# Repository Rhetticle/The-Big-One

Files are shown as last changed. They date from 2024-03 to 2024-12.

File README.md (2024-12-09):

# The Big One

image0 (6)

https://github.com/user-attachments/assets/869daa6d-89cc-4672-a1f7-7d603dca1637

3D printed 3-stage 1kJ projectile accelerator.

## Update
As of Febuary 2024, this device is no longer operational and has been salvaged for parts.
## Safety Notice
* This device was built purely to challenge myself with a complex engineering project to learn about electronics and was never intended to be used as a weapon
* Certain parts of the build have been omitted from the repository to prevent those with malicious intent from replicating this device
## Performance
* Peak exit velocity (All capacitors charged to 385V) - 61 km/h
* Peak exit energy (100g projectile) - 13.9 J
* Efficiency - 1.4%

## Hardware Details
All circuitry and PCBs were custom made, designed in Kicad and manufactured by JLCPCB with hardware provided by Digikey or homemade (e.g. transformer, power inductors etc)
### Capacitors
The Big One uses three 4.5mF 400V chassis mount capacitors. The total energy in these capacitors at max operating voltage (385V) is approximately 1kJ. 
### Capacitor Charger
Capacitors were charged using a ZVS circuit driving a homemade step-up transformer (see below) to increase the 30VAC across the resonant capacitors of the ZVS up to 550VAC to be used to charge the high voltage capacitors. The average power output of this charger was around 300W when charging the entire bank of capacitors from 0V to 385V. 




### Control Board
The control board was mounted in the middle section. It uses an STM32F401RBT6 to control the timing of the three acceleration stages as well as measures the capacitor bank voltage. Four schottky diodes are also on the board to rectify the transformer output.

image0 (10)

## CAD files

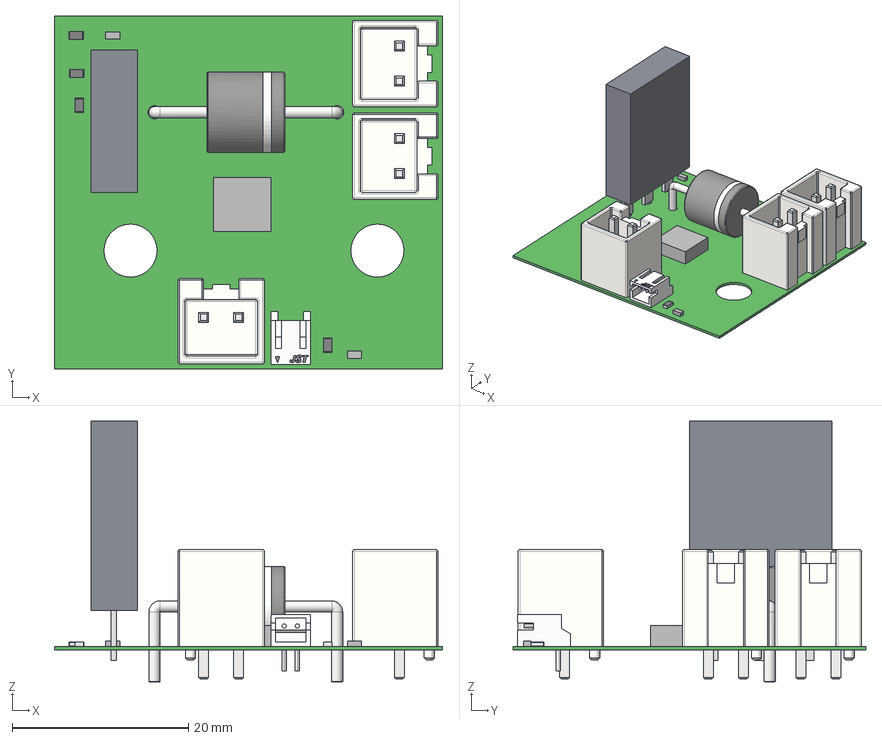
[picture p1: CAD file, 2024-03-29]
PCBs/Firing Board/PCB1.step
44.0 x 40.0 x 29.6 mm
B2P-VH-FB-B x 3
JST Logo adjustable x 3
Extruded x 10
Mid_Body x 4
Mark x 4
Pins
New Marking
JST Logo
Leads
Vishay
mark

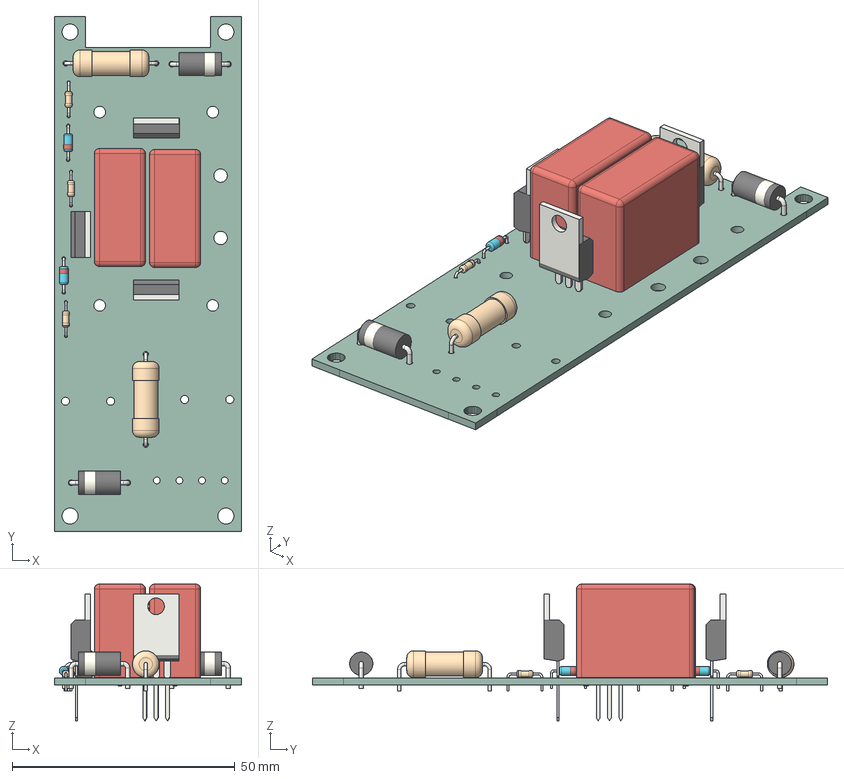
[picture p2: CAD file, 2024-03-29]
PCBs/ZVS/ZVS.step
42.0 x 115.8 x 30.8 mm
PCB

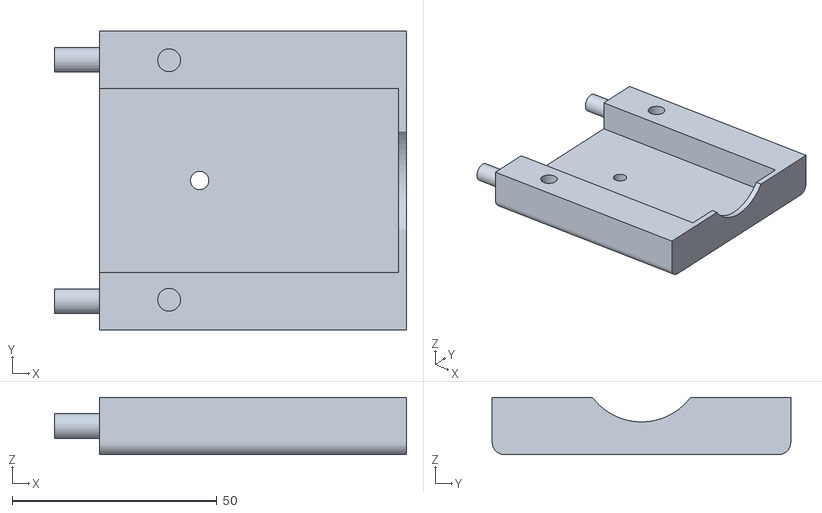
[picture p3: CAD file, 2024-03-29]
TBO CAD/STL Files/Barrel/Barrel Bottom/Barrel bottom short.stl
86.0 x 73.0 x 14.0

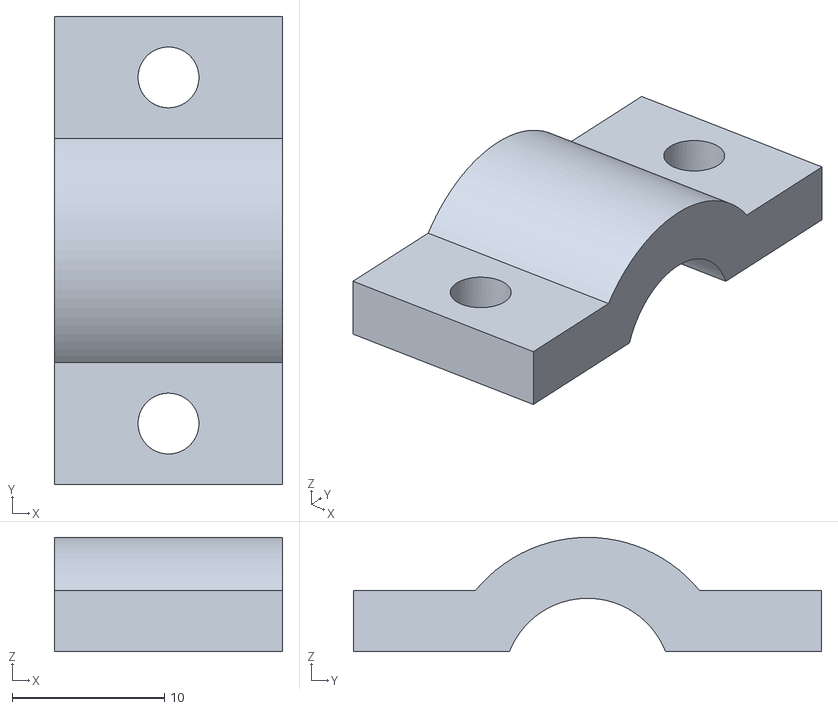
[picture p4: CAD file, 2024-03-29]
TBO CAD/STL Files/Barrel/Barrel clamp.stl
15.0 x 30.7 x 7.50

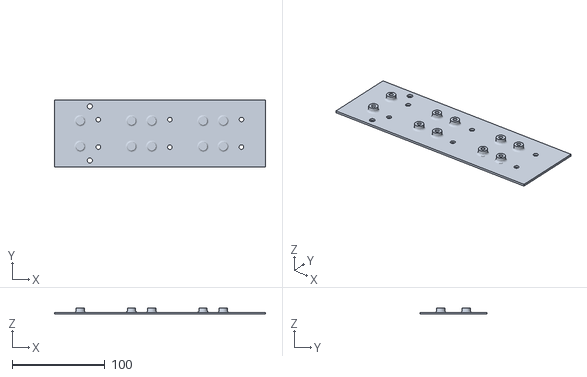
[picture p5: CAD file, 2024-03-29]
TBO CAD/STL Files/Barrel/Barrel Middle/Barrel middle long.stl
228.1 x 73.0 x 7.00

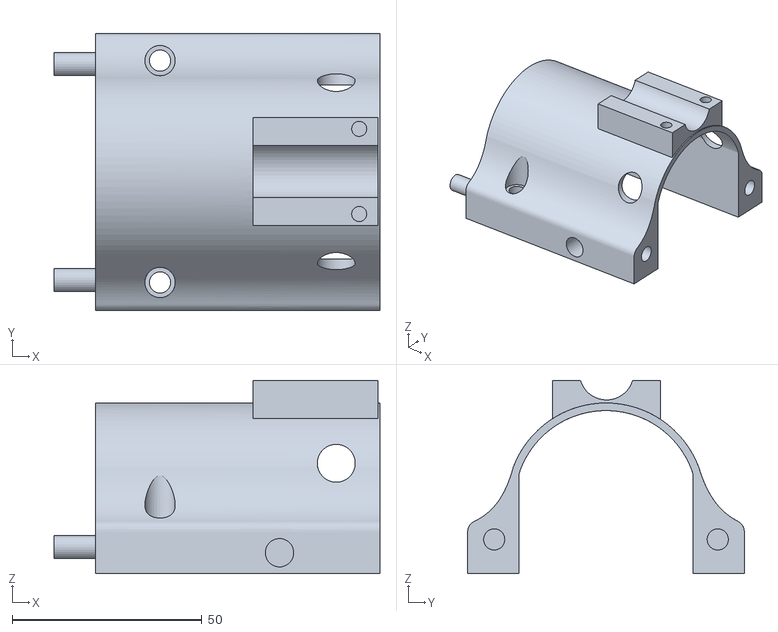
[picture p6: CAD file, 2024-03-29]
TBO CAD/STL Files/Barrel/Barrel Top/Barrel top short.stl
86.0 x 73.0 x 50.9

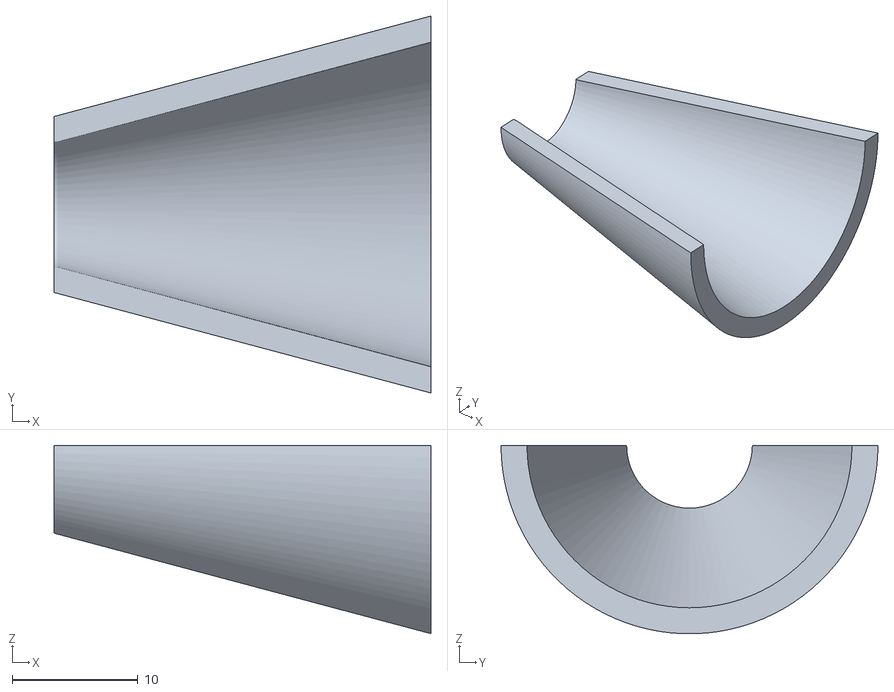
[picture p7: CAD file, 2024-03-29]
TBO CAD/STL Files/Cone/Cone bottom half.stl
30.0 x 30.0 x 15.0

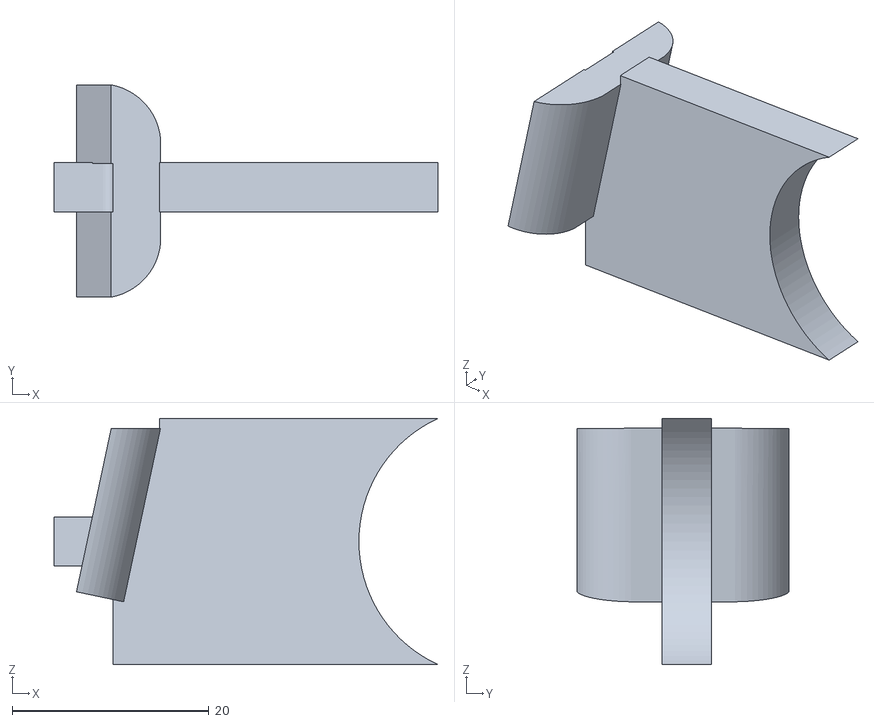
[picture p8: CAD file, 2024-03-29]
TBO CAD/STL Files/Handle/Trigger.stl
39.0 x 21.6 x 25.0

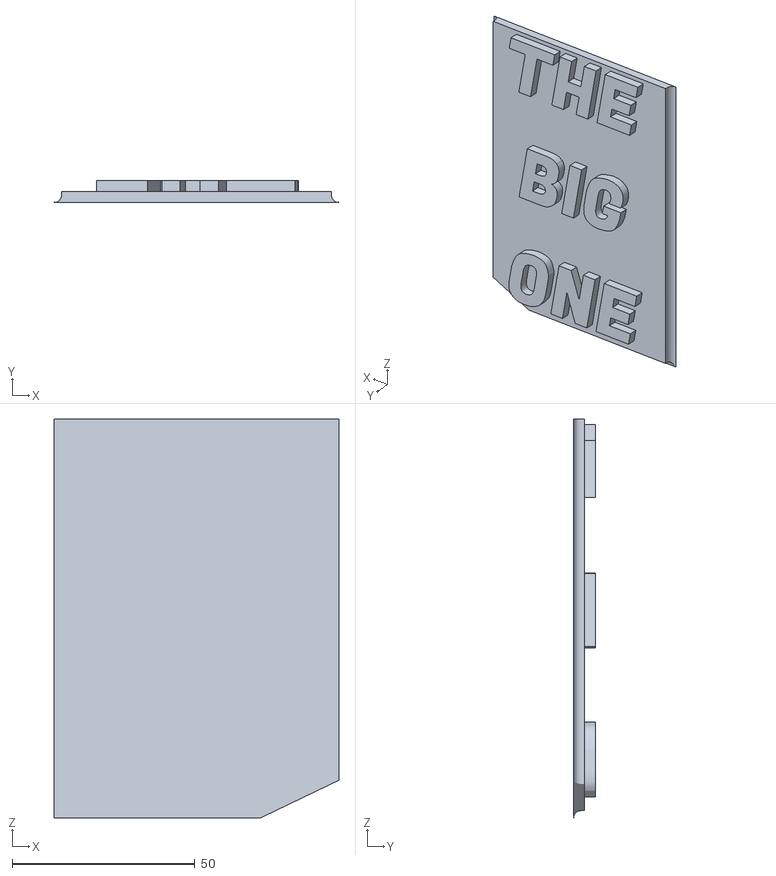
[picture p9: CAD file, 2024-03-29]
TBO CAD/STL Files/Middle/Name.stl
77.9 x 6.00 x 109.1

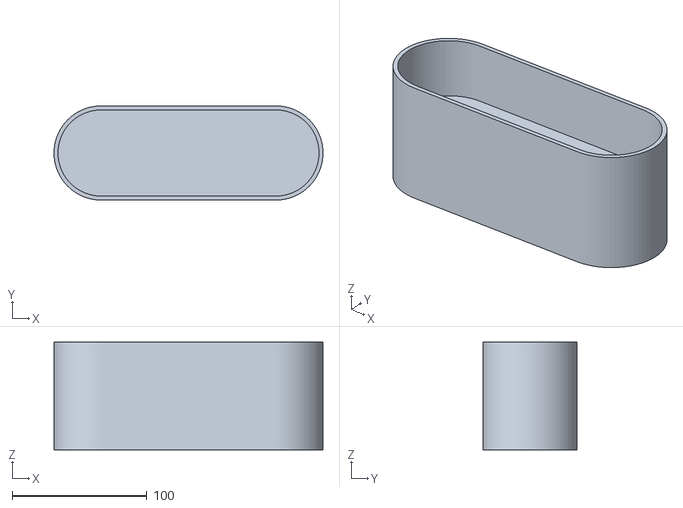
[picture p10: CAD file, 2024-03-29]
TBO CAD/STL Files/Stand.stl
199.9 x 70.0 x 80.0

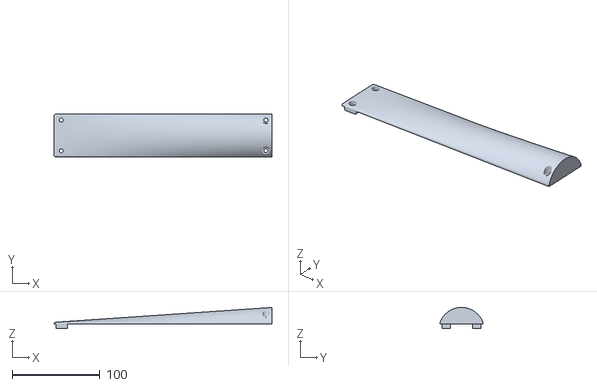
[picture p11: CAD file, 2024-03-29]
TBO CAD/STL Files/Stock/Stock lid.stl
248.8 x 49.0 x 24.1

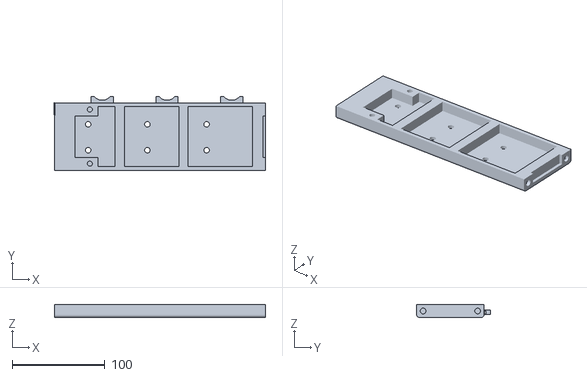
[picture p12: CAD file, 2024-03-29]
TBO CAD/STL Files/Barrel/Barrel Bottom/Barrel bottom long.stl
228.1 x 79.9 x 14.0

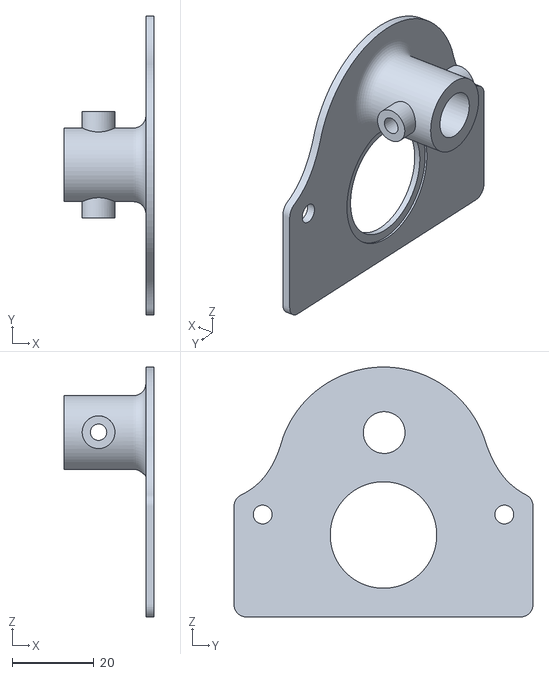
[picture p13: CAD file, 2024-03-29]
TBO CAD/STL Files/Barrel/Barrel front cover.stl
22.0 x 73.0 x 61.0

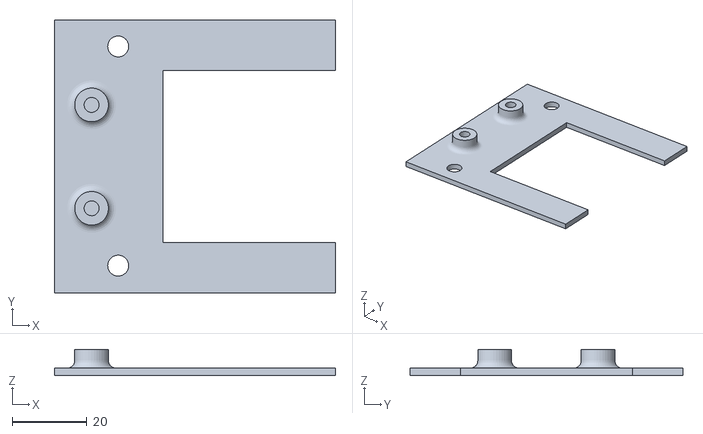
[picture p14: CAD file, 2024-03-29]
TBO CAD/STL Files/Barrel/Barrel Middle/Barrel middle short.stl
75.0 x 73.0 x 7.00

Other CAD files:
TBO CAD/STL Files/Barrel/Barrel Top/Barrel top long.stl
TBO CAD/STL Files/Coil Stop.stl
TBO CAD/STL Files/Cone/Cone top half.stl
TBO CAD/STL Files/Handle/Handle.stl
TBO CAD/STL Files/Barrel/Barrel Top/laser clamp.stl
TBO CAD/STL Files/Bolt Assembly/Bolt guide plug.stl
TBO CAD/STL Files/Bolt Assembly/Bolt guide.stl
TBO CAD/STL Files/Bolt Assembly/Bolt plug.stl
TBO CAD/STL Files/Bolt Assembly/Bolt sphere.stl
TBO CAD/STL Files/Bolt Assembly/Bolt.stl
TBO CAD/STL Files/Foregrip.stl
TBO CAD/STL Files/Middle/Logo.stl
TBO CAD/STL Files/Middle/Middle Section Spacer.stl
TBO CAD/STL Files/Middle/Middle plate.stl
TBO CAD/STL Files/Middle/New Middle.stl
TBO CAD/STL Files/Stock/Battery clip.stl
TBO CAD/STL Files/Stock/New Stock.stl
TBO CAD/STL Files/Stock/transformer compartment lid.stl

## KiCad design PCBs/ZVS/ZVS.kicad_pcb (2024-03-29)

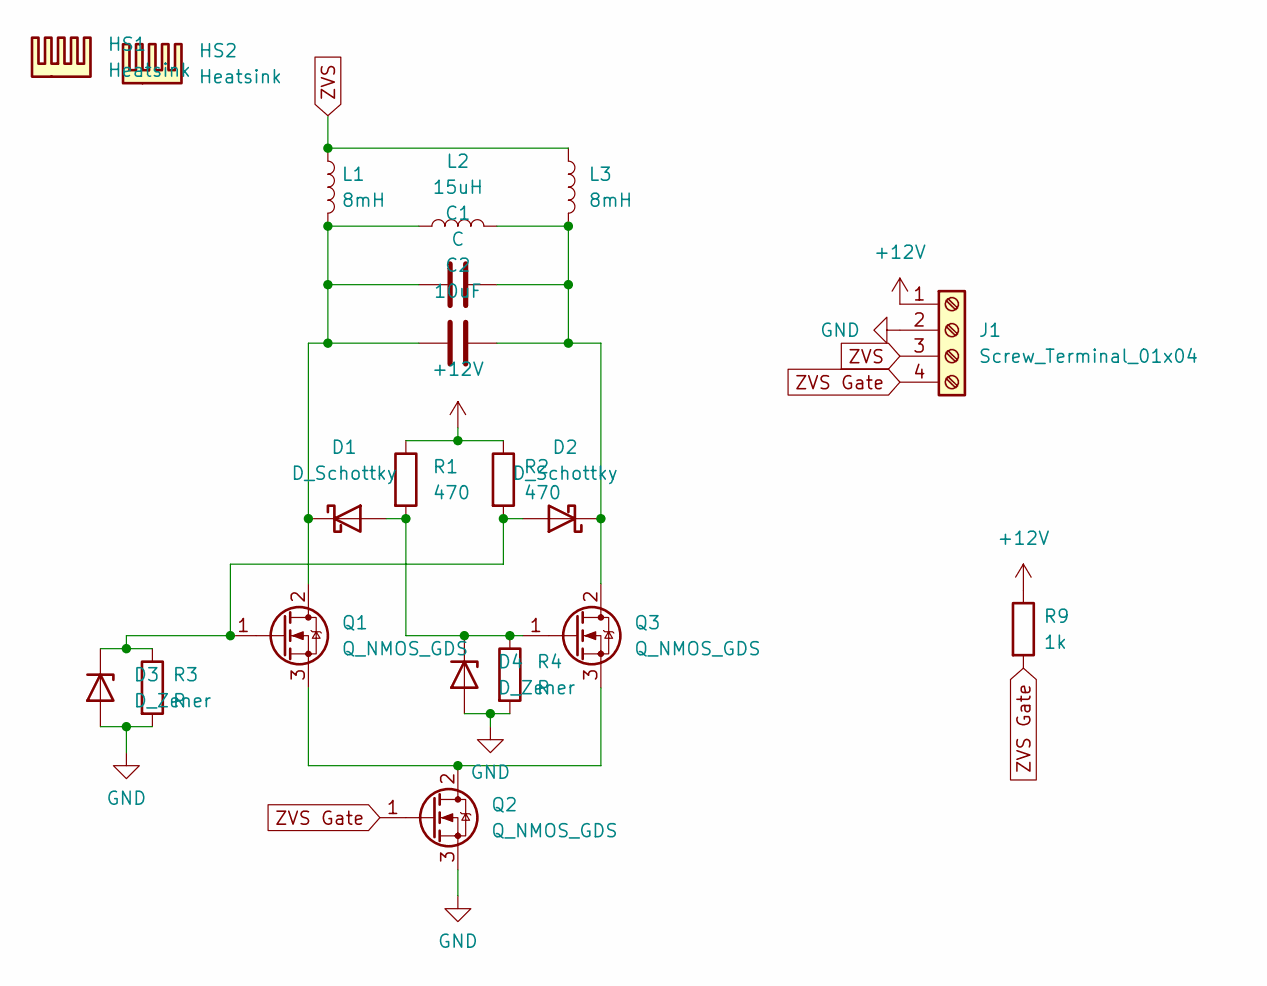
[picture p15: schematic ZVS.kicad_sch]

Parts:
C1: C; C_Rect_L26.5mm_W11.5mm_P22.50mm_MKS4
C2: 10uF; C_Rect_L26.5mm_W11.5mm_P22.50mm_MKS4
D1, D2: D_Schottky; D_DO-201_P12.70mm_Horizontal
D3, D4: D_Zener; D_DO-35_SOD27_P7.62mm_Horizontal
HS1, HS2: Heatsink; 63710ABPE
J1: Screw_Terminal_01x04; TerminalBlock_bornier-4_P5.08mm
L1, L3: 8mH; L_Toroid_Vertical_L26.7mm_W14.0mm_P10.16mm_Pulse_D
L2: 15uH; Primary
Q1, Q2, Q3: Q_NMOS_GDS; TO-220-3_Vertical
R1, R2: 470; R_Axial_DIN0617_L17.0mm_D6.0mm_P20.32mm_Horizontal
R3, R4: R; R_Axial_DIN0204_L3.6mm_D1.6mm_P7.62mm_Horizontal
R9: 1k; R_Axial_DIN0204_L3.6mm_D1.6mm_P7.62mm_Horizontal

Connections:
+12V: J1.1, R1.1, R2.1, R9.1
GND: D3.2 (A), D4.2 (A), J1.2, Q2.3 (S), R3.2, R4.2
unnamed: C1.1, C2.1, D1.1 (K), L1.2, L2.1, Q1.2 (D)
unnamed: C1.2, C2.2, D2.1 (K), L2.2, L3.2, Q3.2 (D)
unnamed: D1.2 (A), D4.1 (K), Q3.1 (G), R1.2, R4.1
unnamed: D2.2 (A), D3.1 (K), Q1.1 (G), R2.2, R3.1
unnamed: Q1.3 (S), Q2.2 (D), Q3.3 (S)
ZVS: J1.3, L1.1, L3.1
ZVS Gate: J1.4, Q2.1 (G), R9.2

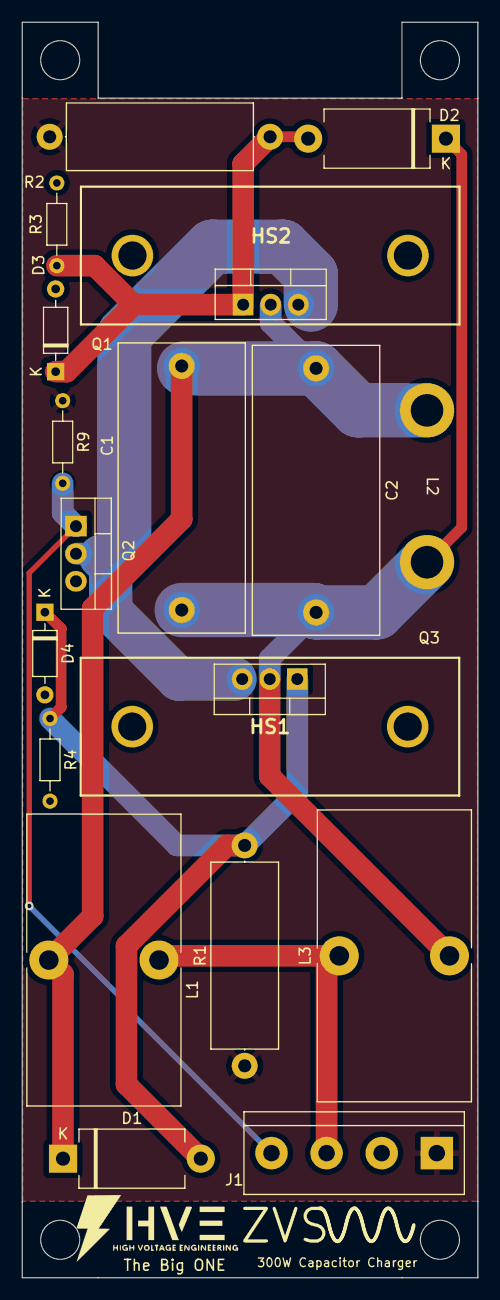
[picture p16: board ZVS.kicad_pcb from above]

Board: 2 copper layers, 42.0 x 115.8 mm, 20 parts (0 on the bottom side), 9 nets.

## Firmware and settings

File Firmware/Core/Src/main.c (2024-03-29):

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
/* Includes ------------------------------------------------------------------*/
#include "main.h"
#include "cmsis_os.h"
#include "usb_device.h"

/* USER CODE BEGIN Includes */
#include "usbd_cdc_if.h"
#include "usbd_core.h"
#include "string.h"
#include "queue.h"
#include "semphr.h"
/* USER CODE END Includes */

ADC_HandleTypeDef hadc1;
DMA_HandleTypeDef hdma_adc1;

TIM_HandleTypeDef htim3;
TIM_HandleTypeDef htim4;
TIM_HandleTypeDef htim10;

/* Definitions for USB_Listen */
osThreadId_t USB_ListenHandle;
const osThreadAttr_t USB_Listen_attributes = {
  .name = "USB_Listen",
  .stack_size = 128 * 4,
  .priority = (osPriority_t) osPriorityAboveNormal,
};
/* Definitions for CheckZVS */
osThreadId_t CheckZVSHandle;
const osThreadAttr_t CheckZVS_attributes = {
  .name = "CheckZVS",
  .stack_size = 128 * 4,
  .priority = (osPriority_t) osPriorityNormal,
};
/* Definitions for LEDStandby */
osThreadId_t LEDStandbyHandle;
const osThreadAttr_t LEDStandby_attributes = {
  .name = "LEDStandby",
  .stack_size = 128 * 4,
  .priority = (osPriority_t) osPriorityNormal,
};
/* Definitions for SelfTest */
osThreadId_t SelfTestHandle;
const osThreadAttr_t SelfTest_attributes = {
  .name = "SelfTest",
  .stack_size = 128 * 4,
  .priority = (osPriority_t) osPriorityAboveNormal,
};
/* Definitions for ProcessADC */
osThreadId_t ProcessADCHandle;
const osThreadAttr_t ProcessADC_attributes = {
  .name = "ProcessADC",
  .stack_size = 256 * 4,
  .priority = (osPriority_t) osPriorityHigh,
};
/* Definitions for LED_Control */
osThreadId_t LED_ControlHandle;
const osThreadAttr_t LED_Control_attributes = {
  .name = "LED_Control",
  .stack_size = 128 * 4,
  .priority = (osPriority_t) osPriorityAboveNormal5,
};
/* Definitions for FiringSeq */
osThreadId_t FiringSeqHandle;
const osThreadAttr_t FiringSeq_attributes = {
  .name = "FiringSeq",
  .stack_size = 128 * 4,
  .priority = (osPriority_t) osPriorityHigh,
};
/* Definitions for ZVStoVcap */
osMessageQueueId_t ZVStoVcapHandle;
const osMessageQueueAttr_t ZVStoVcap_attributes = {
  .name = "ZVStoVcap"
};
/* Definitions for ISRtoProcessADC */
osMessageQueueId_t ISRtoProcessADCHandle;
const osMessageQueueAttr_t ISRtoProcessADC_attributes = {
  .name = "ISRtoProcessADC"
};
/* Definitions for ProcessADCtoLED */
osMessageQueueId_t ProcessADCtoLEDHandle;
const osMessageQueueAttr_t ProcessADCtoLED_attributes = {
  .name = "ProcessADCtoLED"
};
/* Definitions for FiringData */
osMessageQueueId_t FiringDataHandle;
const osMessageQueueAttr_t FiringData_attributes = {
  .name = "FiringData"
};
/* Definitions for LEDs */
osMutexId_t LEDsHandle;
const osMutexAttr_t LEDs_attributes = {
  .name = "LEDs"
};
/* USER CODE BEGIN PV */
extern USBD_HandleTypeDef hUsbDeviceFS;
/* USER CODE END PV */

void SystemClock_Config(void);
static void MX_GPIO_Init(void);
static void MX_DMA_Init(void);
static void MX_TIM3_Init(void);
static void MX_ADC1_Init(void);
static void MX_TIM4_Init(void);
static void MX_TIM10_Init(void);
void USB_Listen_Start(void *argument);
void StartCheckZVS(void *argument);
void StartLEDStandby(void *argument);
void StartSelfTest(void *argument);
void StartProcessADC(void *argument);
void StartLED_Control(void *argument);
void StartFiringSeq(void *argument);

/* USER CODE BEGIN 0 */
char buffer[64];
uint8_t rec_cplt;
uint8_t trig_count=0;
uint32_t ADC_raw[2];
uint16_t c_delay=0;
uint32_t Vcap_prev=0;

#define ERR_OVER_CHRG 1;

void delay(uint16_t dely){

	__HAL_TIM_SET_COUNTER(&htim3,0);
	while(__HAL_TIM_GET_COUNTER(&htim3)<dely);

}

void LED_Reset(void){
	HAL_GPIO_WritePin(GPIOB, GPIO_PIN_8, 0);
	HAL_GPIO_WritePin(GPIOB, GPIO_PIN_9, 0);
	HAL_GPIO_WritePin(GPIOB, GPIO_PIN_15, 0);
	HAL_GPIO_WritePin(GPIOB, GPIO_PIN_14, 0);
	HAL_GPIO_WritePin(GPIOB, GPIO_PIN_13, 0);
	HAL_GPIO_WritePin(GPIOB, GPIO_PIN_12, 0);
	HAL_GPIO_WritePin(GPIOB, GPIO_PIN_10, 0);
}

void LED_Follow(void){
	HAL_GPIO_WritePin(GPIOB, GPIO_PIN_10, 1);
	osDelay(100);
	HAL_GPIO_WritePin(GPIOB, GPIO_PIN_12, 1);
	osDelay(100);
	HAL_GPIO_WritePin(GPIOB, GPIO_PIN_13, 1);
	osDelay(100);
	HAL_GPIO_WritePin(GPIOB, GPIO_PIN_14, 1);
	osDelay(100);
	HAL_GPIO_WritePin(GPIOB, GPIO_PIN_15, 1);
	osDelay(100);
	HAL_GPIO_WritePin(GPIOB, GPIO_PIN_9, 1);
	osDelay(100);
	HAL_GPIO_WritePin(GPIOB, GPIO_PIN_9, 0);
	osDelay(100);
	HAL_GPIO_WritePin(GPIOB, GPIO_PIN_15, 0);
	osDelay(100);
	HAL_GPIO_WritePin(GPIOB, GPIO_PIN_14, 0);
	osDelay(100);
	HAL_GPIO_WritePin(GPIOB, GPIO_PIN_13, 0);
	osDelay(100);
	HAL_GPIO_WritePin(GPIOB, GPIO_PIN_12, 0);
	osDelay(100);
	HAL_GPIO_WritePin(GPIOB, GPIO_PIN_10, 0);
	osDelay(100);
}

void LED_Flash(void){
	HAL_GPIO_WritePin(GPIOB, GPIO_PIN_10, 1);
	HAL_GPIO_WritePin(GPIOB, GPIO_PIN_12, 1);
	HAL_GPIO_WritePin(GPIOB, GPIO_PIN_13, 1);
	HAL_GPIO_WritePin(GPIOB, GPIO_PIN_14, 1);
	HAL_GPIO_WritePin(GPIOB, GPIO_PIN_15, 1);
	HAL_GPIO_WritePin(GPIOB, GPIO_PIN_9, 1);
	HAL_GPIO_WritePin(GPIOB, GPIO_PIN_8, 1);
	osDelay(1000);
	HAL_GPIO_WritePin(GPIOB, GPIO_PIN_8, 0);
	HAL_GPIO_WritePin(GPIOB, GPIO_PIN_9, 0);
	HAL_GPIO_WritePin(GPIOB, GPIO_PIN_15, 0);
	HAL_GPIO_WritePin(GPIOB, GPIO_PIN_14, 0);
	HAL_GPIO_WritePin(GPIOB, GPIO_PIN_13, 0);
	HAL_GPIO_WritePin(GPIOB, GPIO_PIN_12, 0);
	HAL_GPIO_WritePin(GPIOB, GPIO_PIN_10, 0);
	osDelay(1000);

}

void chrg_led_reset(void){

	HAL_GPIO_WritePin(GPIOB, GPIO_PIN_10, 0);
	HAL_GPIO_WritePin(GPIOB, GPIO_PIN_12, 0);
	HAL_GPIO_WritePin(GPIOB, GPIO_PIN_13, 0);
	HAL_GPIO_WritePin(GPIOB, GPIO_PIN_14, 0);
}

void overcharge(void){
	HAL_GPIO_WritePin(GPIOB, GPIO_PIN_14, 1);
	osDelay(100);
	HAL_GPIO_WritePin(GPIOB, GPIO_PIN_14, 0);
	osDelay(100);

}

void led_quick_flash(void){
	HAL_GPIO_WritePin(GPIOB, GPIO_PIN_10, 1);
	HAL_GPIO_WritePin(GPIOB, GPIO_PIN_12, 1);
	HAL_GPIO_WritePin(GPIOB, GPIO_PIN_13, 1);
	HAL_GPIO_WritePin(GPIOB, GPIO_PIN_14, 1);
	HAL_GPIO_WritePin(GPIOB, GPIO_PIN_15, 1);
	HAL_GPIO_WritePin(GPIOB, GPIO_PIN_9, 1);
	osDelay(100);
	HAL_GPIO_WritePin(GPIOB, GPIO_PIN_9, 0);
	HAL_GPIO_WritePin(GPIOB, GPIO_PIN_15, 0);
	HAL_GPIO_WritePin(GPIOB, GPIO_PIN_14, 0);
	HAL_GPIO_WritePin(GPIOB, GPIO_PIN_13, 0);
	HAL_GPIO_WritePin(GPIOB, GPIO_PIN_12, 0);
	HAL_GPIO_WritePin(GPIOB, GPIO_PIN_10, 0);
	osDelay(100);
}

int Charge_val_round(uint32_t ADC_val){
	if(ADC_val<100){
		ADC_val=100;
	}

	if(ADC_val>100 && ADC_val<250){
		ADC_val=250;
	}

	if(ADC_val>250 && ADC_val<385){
		ADC_val=385;
	}

	if(ADC_val>385){
		ADC_val=400;
	}

	return(ADC_val);
}


void HAL_GPIO_EXTI_Callback(uint16_t GPIO_Pin){
	if(trig_count==1){
		return;
	}
	if(GPIO_Pin==GPIO_PIN_10){
		trig_count=1;


	}

}

void HAL_TIM_PWM_PulseFinishedCallback(TIM_HandleTypeDef *htim){
	HAL_ADC_Start_DMA(&hadc1, ADC_raw, 2);
}

void HAL_ADC_ConvCpltCallback(ADC_HandleTypeDef *hadc){
	if(ADC_raw[0]>Vcap_prev){
		Vcap_prev=ADC_raw[0];
	}
	BaseType_t xYieldRequired;
	xQueueSendFromISR(ISRtoProcessADCHandle,&Vcap_prev,NULL);
	xQueueSendFromISR(ISRtoProcessADCHandle,&ADC_raw[1],NULL);
	xYieldRequired = xTaskResumeFromISR(ProcessADCHandle);
	portYIELD_FROM_ISR( xYieldRequired );
}

/* USER CODE END 0 */

/**
  * @brief  The application entry point.
  * @retval int
  */
int main(void)
{
  /* MCU Configuration--------------------------------------------------------*/

  /* Reset of all peripherals, Initializes the Flash interface and the Systick. */
  HAL_Init();

  /* Configure the system clock */
  SystemClock_Config();

  /* Initialize all configured peripherals */
  MX_GPIO_Init();
  MX_DMA_Init();
  MX_TIM3_Init();
  MX_ADC1_Init();
  MX_TIM4_Init();
  MX_TIM10_Init();
  /* USER CODE BEGIN 2 */
  MX_USB_DEVICE_Init();
  HAL_TIM_Base_Start(&htim3);
  HAL_TIM_PWM_Start_IT(&htim4, TIM_CHANNEL_1);
  TIM4->CCR1=2000-1;
  /* USER CODE END 2 */

  /* Init scheduler */
  osKernelInitialize();
  /* Create the mutex(es) */
  /* creation of LEDs */
  LEDsHandle = osMutexNew(&LEDs_attributes);

  /* USER CODE BEGIN RTOS_MUTEX */
  /* add mutexes, ... */
  xSemaphoreGive(LEDsHandle);
  /* USER CODE END RTOS_MUTEX */

  /* USER CODE BEGIN RTOS_SEMAPHORES */
  /* add semaphores, ... */
  /* USER CODE END RTOS_SEMAPHORES */

  /* USER CODE BEGIN RTOS_TIMERS */
  /* start timers, add new ones, ... */
  /* USER CODE END RTOS_TIMERS */

  /* Create the queue(s) */
  /* creation of ZVStoVcap */
  ZVStoVcapHandle = osMessageQueueNew (1, sizeof(uint32_t), &ZVStoVcap_attributes);

  /* creation of ISRtoProcessADC */
  ISRtoProcessADCHandle = osMessageQueueNew (2, sizeof(uint32_t), &ISRtoProcessADC_attributes);

  /* creation of ProcessADCtoLED */
  ProcessADCtoLEDHandle = osMessageQueueNew (1, sizeof(uint32_t), &ProcessADCtoLED_attributes);

  /* creation of FiringData */
  FiringDataHandle = osMessageQueueNew (2, sizeof(uint32_t), &FiringData_attributes);

  /* USER CODE BEGIN RTOS_QUEUES */
  /* add queues, ... */
  /* USER CODE END RTOS_QUEUES */

  /* Create the thread(s) */
  /* creation of USB_Listen */
  USB_ListenHandle = osThreadNew(USB_Listen_Start, NULL, &USB_Listen_attributes);

  /* creation of CheckZVS */
  CheckZVSHandle = osThreadNew(StartCheckZVS, NULL, &CheckZVS_attributes);

  /* creation of LEDStandby */
  LEDStandbyHandle = osThreadNew(StartLEDStandby, NULL, &LEDStandby_attributes);

  /* creation of SelfTest */
  SelfTestHandle = osThreadNew(StartSelfTest, NULL, &SelfTest_attributes);

  /* creation of ProcessADC */
  ProcessADCHandle = osThreadNew(StartProcessADC, NULL, &ProcessADC_attributes);

  /* creation of LED_Control */
  LED_ControlHandle = osThreadNew(StartLED_Control, NULL, &LED_Control_attributes);

  /* creation of FiringSeq */
  FiringSeqHandle = osThreadNew(StartFiringSeq, NULL, &FiringSeq_attributes);

  /* USER CODE BEGIN RTOS_THREADS */
  /* add threads, ... */
  /* USER CODE END RTOS_THREADS */

  /* USER CODE BEGIN RTOS_EVENTS */
  /* add events, ... */
  /* USER CODE END RTOS_EVENTS */

  /* Start scheduler */
  osKernelStart();
  /* We should never get here as control is now taken by the scheduler */
  /* Infinite loop */
  /* USER CODE BEGIN WHILE */

  while (1)
  {
    /* USER CODE END WHILE */

    /* USER CODE BEGIN 3 */
  }
  /* USER CODE END 3 */
}

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
/* USER CODE BEGIN Header_USB_Listen_Start */
/**
  * @brief  Function implementing the USB_Listen thread.
  * @param  argument: Not used
  * @retval None
  */
/* USER CODE END Header_USB_Listen_Start */
void USB_Listen_Start(void *argument)
{
  /* init code for USB_DEVICE */
  MX_USB_DEVICE_Init();
  /* USER CODE BEGIN 5 */
  HAL_TIM_Base_Start(&htim3);
  /* Infinite loop */
  for(;;)
  {
	  char mess[64];

	  if(rec_cplt==1){
		  if(strcmp(buffer,"C1")==0){
			  HAL_GPIO_WritePin(GPIOA, GPIO_PIN_7, 1);
			  HAL_GPIO_WritePin(GPIOA, GPIO_PIN_6, 1);
			  HAL_Delay(1000);
			  HAL_GPIO_WritePin(GPIOA, GPIO_PIN_7, 0);
			  HAL_GPIO_WritePin(GPIOA, GPIO_PIN_6, 0);
			  HAL_Delay(1000);
			  rec_cplt=0;
		  }

		  else{
			  c_delay=atoi(buffer);
			  sprintf(mess,"Delay set to %i us",c_delay);
			  CDC_Transmit_FS(mess, strlen(mess));
		  }





	  }
	  vTaskSuspend(NULL);

  }
  /* USER CODE END 5 */
}

/* USER CODE BEGIN Header_StartCheckZVS */
/**
* @brief Function implementing the CheckZVS thread.
* @param argument: Not used
* @retval None
*/
/* USER CODE END Header_StartCheckZVS */
void StartCheckZVS(void *argument)
{
  /* USER CODE BEGIN StartCheckZVS */
  /* Infinite loop */
  for(;;)
  {

	 if(trig_count==0){
		 vTaskSuspend(NULL);
	 }
	 if(trig_count==1){

		 if(ulTaskNotifyTake(pdTRUE, 0)==1){

		 }

		 else{
			 if(HAL_GPIO_ReadPin(GPIOA, GPIO_PIN_10)==0){

			 					 osDelay(2000);
			 					 if(HAL_GPIO_ReadPin(GPIOA, GPIO_PIN_10)==0){
			 						HAL_GPIO_WritePin(GPIOA, GPIO_PIN_7, 1);
			 						osDelay(c_delay);
			 						HAL_GPIO_WritePin(GPIOA, GPIO_PIN_6, 1);
			 						osDelay(100);
			 						HAL_GPIO_WritePin(GPIOA, GPIO_PIN_5, 1);
			 						osDelay(10);
			 						HAL_GPIO_WritePin(GPIOA, GPIO_PIN_7, 0);
			 						HAL_GPIO_WritePin(GPIOA, GPIO_PIN_6, 0);
			 						HAL_GPIO_WritePin(GPIOA, GPIO_PIN_5,0);
			 					    vTaskSuspend(NULL); //Resumed in Vcap
			 					 	}



			 			 	}
		 }
		 }

	 }


  /* USER CODE END StartCheckZVS */
}

/* USER CODE BEGIN Header_StartLEDStandby */
/**
* @brief Function implementing the LEDStandby thread.
* @param argument: Not used
* @retval None
*/
/* USER CODE END Header_StartLEDStandby */
void StartLEDStandby(void *argument)
{
  /* USER CODE BEGIN StartLEDStandby */
  /* Infinite loop */
  for(;;)
  {

		 LED_Flash();

  }
  /* USER CODE END StartLEDStandby */
}

/* USER CODE BEGIN Header_StartSelfTest */
/**
* @brief Function implementing the SelfTest thread.
* @param argument: Not used
* @retval None
*/
/* USER CODE END Header_StartSelfTest */
void StartSelfTest(void *argument)
{
  /* USER CODE BEGIN StartSelfTest */
  /* Infinite loop */
  for(;;)
  {

    if(trig_count==1){
    	vTaskSuspend(LEDStandbyHandle);
    	xSemaphoreTake(LEDsHandle,portMAX_DELAY);
    	LED_Reset();
    	LED_Follow();
    	LED_Follow();
    	LED_Follow();
    	xSemaphoreGive(LEDsHandle);
    	vTaskResume(LED_ControlHandle);
    	vTaskResume(CheckZVSHandle);
    	vTaskResume(FiringSeqHandle);
    	vTaskSuspend(NULL);
    }
    osDelay(1);
  }
  /* USER CODE END StartSelfTest */
}

/* USER CODE BEGIN Header_StartProcessADC */
/**
* @brief Function implementing the ProcessADC thread.
* @param argument: Not used
* @retval None
*/
/* USER CODE END Header_StartProcessADC */
void StartProcessADC(void *argument)
{
  /* USER CODE BEGIN StartProcessADC */
  /* Infinite loop */
  for(;;)
  {

	if(trig_count==1){
		vTaskResume(LED_ControlHandle);
	}
	uint32_t ADC_vals[2];
	int Vcap;
	int Charge_val;
    xQueueReceive(ISRtoProcessADCHandle, &ADC_vals[0], 0); //Receive Capacitor voltage
    xQueueReceive(ISRtoProcessADCHandle, &ADC_vals[1], 0); //Receive Capacitor voltage
    Vcap=((float)ADC_vals[0]/4095)*729.3;
    Charge_val=((float)ADC_vals[1]/4095)*400*(-1)+400;
    Charge_val=Charge_val_round(Charge_val);

    if(Vcap==Charge_val || Vcap>Charge_val){
    	HAL_GPIO_WritePin(GPIOB, GPIO_PIN_9, 1);
    	vTaskResume(FiringSeqHandle);

    }

    CDC_Transmit_FS(&Vcap, 2);
    osDelay(100);
    xQueueSend(ProcessADCtoLEDHandle,&Charge_val,0);
    vTaskSuspend(NULL);


  }
  /* USER CODE END StartProcessADC */
}

/* USER CODE BEGIN Header_StartLED_Control */
/**
* @brief Function implementing the LED_Control thread.
* @param argument: Not used
* @retval None
*/
/* USER CODE END Header_StartLED_Control */
void StartLED_Control(void *argument)
{
  /* USER CODE BEGIN StartLED_Control */
  /* Infinite loop */
  for(;;)
  {
	int Charge_val=0;
	xQueueReceive(ProcessADCtoLEDHandle, &Charge_val, 0);
    if(trig_count==0){
    	vTaskSuspend(NULL);
    }
    xSemaphoreTake(LEDsHandle,portMAX_DELAY); //Take control of LED GPIOs

       	if(Charge_val==100){
       		    HAL_TIM_Base_Stop_IT(&htim10);
       	    	chrg_led_reset();
       	    	HAL_GPIO_WritePin(GPIOB, GPIO_PIN_10, 1);
       	    	vTaskResume(CheckZVSHandle);
       	    }

       	if(Charge_val==250){
       		    HAL_TIM_Base_Stop_IT(&htim10);
       		    chrg_led_reset();
       	    	HAL_GPIO_WritePin(GPIOB, GPIO_PIN_10, 1);
       	    	HAL_GPIO_WritePin(GPIOB, GPIO_PIN_12, 1);
       	    	vTaskResume(CheckZVSHandle);
       	    }

       	if(Charge_val==385){
       		    HAL_TIM_Base_Stop_IT(&htim10);
       		    chrg_led_reset();
       	    	HAL_GPIO_WritePin(GPIOB, GPIO_PIN_10, 1);
       	    	HAL_GPIO_WritePin(GPIOB, GPIO_PIN_12, 1);
       	    	HAL_GPIO_WritePin(GPIOB, GPIO_PIN_13, 1);
       	    	vTaskResume(CheckZVSHandle);
       	    }

       if(Charge_val>385){
       	    	HAL_GPIO_WritePin(GPIOB, GPIO_PIN_10, 1);
       	    	HAL_GPIO_WritePin(GPIOB, GPIO_PIN_12, 1);
       	    	HAL_GPIO_WritePin(GPIOB, GPIO_PIN_13, 1);
       	    	if(HAL_GPIO_ReadPin(GPIOA, GPIO_PIN_10)==0){
       	    		HAL_TIM_Base_Stop_IT(&htim10);
       	    		LED_Reset();
       	    		led_quick_flash();
       	    		led_quick_flash();
       	    		led_quick_flash();
       	    	}
       	    	else{
       	    		HAL_TIM_Base_Start_IT(&htim10);
       	    	}

       	    }
       xSemaphoreGive(LEDsHandle); //Release control of LED GPIOs
       vTaskSuspend(NULL);



  }
  /* USER CODE END StartLED_Control */
}

/* USER CODE BEGIN Header_StartFiringSeq */
/**
* @brief Function implementing the FiringSeq thread.
* @param argument: Not used
* @retval None
*/
/* USER CODE END Header_StartFiringSeq */
void StartFiringSeq(void *argument)
{
  /* USER CODE BEGIN StartFiringSeq */
  /* Infinite loop */
  for(;;)
  {
    if(trig_count==0){
    	vTaskSuspend(NULL);
    }

    HAL_GPIO_WritePin(GPIOC, GPIO_PIN_10, 0); //Turn off ZVS





    	HAL_GPIO_WritePin(GPIOB, GPIO_PIN_8, 1);

    	if(HAL_GPIO_ReadPin(GPIOA, GPIO_PIN_10)==0){ //Check Trigger
    	    	HAL_GPIO_WritePin(GPIOA, GPIO_PIN_7, 1);
    	    	delay(c_delay);
    	    	HAL_GPIO_WritePin(GPIOA, GPIO_PIN_6, 1);
    	    	osDelay(100);
    	    	HAL_GPIO_WritePin(GPIOA, GPIO_PIN_5, 1);
    	    	osDelay(10);
    	    	HAL_GPIO_WritePin(GPIOA, GPIO_PIN_7, 0);
    	    	HAL_GPIO_WritePin(GPIOA, GPIO_PIN_6, 0);
    	    	HAL_GPIO_WritePin(GPIOA, GPIO_PIN_5,0);
    	    	Vcap_prev=0;
    	    	osDelay(100);
    	    	HAL_GPIO_WritePin(GPIOB, GPIO_PIN_9, 0);
    	    	HAL_GPIO_WritePin(GPIOB, GPIO_PIN_8, 0);
    	}





    vTaskResume(CheckZVSHandle); //Resume checking of ZVS
    vTaskSuspend(NULL);
  }
  /* USER CODE END StartFiringSeq */
}

/**
  * @brief  Period elapsed callback in non blocking mode
  * @note   This function is called  when TIM2 interrupt took place, inside
  * HAL_TIM_IRQHandler(). It makes a direct call to HAL_IncTick() to increment
  * a global variable "uwTick" used as application time base.
  * @param  htim : TIM handle
  * @retval None
  */
void HAL_TIM_PeriodElapsedCallback(TIM_HandleTypeDef *htim)
{
  /* USER CODE BEGIN Callback 0 */
  if(htim->Instance== TIM10){
	  HAL_GPIO_TogglePin(GPIOB, GPIO_PIN_14);
  }
  /* USER CODE END Callback 0 */
  if (htim->Instance == TIM2) {
    HAL_IncTick();
  }
}

/**
  * @brief  This function is executed in case of error occurrence.
  * @retval None
  */
void Error_Handler(void)
{
  /* USER CODE BEGIN Error_Handler_Debug */
  /* User can add his own implementation to report the HAL error return state */
  __disable_irq();
  while (1)
  {
  }
  /* USER CODE END Error_Handler_Debug */
}

#ifdef  USE_FULL_ASSERT
/**
  * @brief  Reports the name of the source file and the source line number
  *         where the assert_param error has occurred.
  * @param  file: pointer to the source file name
  * @param  line: assert_param error line source number
  * @retval None
  */
void assert_failed(uint8_t *file, uint32_t line)
{
  /* USER CODE BEGIN 6 */
  /* User can add his own implementation to report the file name and line number,
     ex: printf("Wrong parameters value: file %s on line %d\r\n", file, line) */
  /* USER CODE END 6 */
}
#endif /* USE_FULL_ASSERT */

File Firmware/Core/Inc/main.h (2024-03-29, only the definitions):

#define CAP_Pin GPIO_PIN_2
#define CAP_GPIO_Port GPIOA
#define V_cap_set_Pin GPIO_PIN_3
#define V_cap_set_GPIO_Port GPIOA
#define ZVS_Pin GPIO_PIN_8
#define ZVS_GPIO_Port GPIOA
#define Safety_Pin GPIO_PIN_9
#define Safety_GPIO_Port GPIOA
#define Trigger_Interupt_Pin GPIO_PIN_10
#define Trigger_Interupt_GPIO_Port GPIOA
#define Trigger_Interupt_EXTI_IRQn EXTI15_10_IRQn
#define ZVS_ON_Pin GPIO_PIN_10
#define ZVS_ON_GPIO_Port GPIOC

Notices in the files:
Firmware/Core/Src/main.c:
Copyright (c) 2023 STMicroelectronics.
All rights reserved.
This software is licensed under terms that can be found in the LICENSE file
